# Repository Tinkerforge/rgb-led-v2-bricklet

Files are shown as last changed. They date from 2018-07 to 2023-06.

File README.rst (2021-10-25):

RGB LED Bricklet 2.0
====================

This repository contains the firmware source code and the hardware design
files. The documentation generator configs can be found at
https://github.com/Tinkerforge/generators

Repository Content
------------------

software/:
 * examples/: Examples for all supported languages
 * build/: Compiled files
 * src/: Source code of firmware
 * Makefile: Makefile to build project

hardware/:
 * Contains KiCad project files and additionally schematics as PDF

datasheets/:
 * Contains datasheets for sensors and complex ICs that are used

Hardware
--------

The hardware is designed with the open source EDA Suite KiCad
(http://www.kicad.org). Before you are able to open the files,
you have to install the Tinkerforge kicad-libraries
(https://github.com/Tinkerforge/kicad-libraries). You can either clone
them directly in hardware/ or clone them in a separate folder and
symlink them into hardware/
(ln -s kicad_path/kicad-libraries project_path/hardware). After that you
can open the .pro file in hardware/ with KiCad and from there view and
modify the schematics and the PCB layout.

Software
--------

If you want to do your own Brick/Bricklet firmware development we highly
recommend that you use our build environment setup script and read the
tutorial (https://www.tinkerforge.com/en/doc/Tutorials/Tutorial_Build_Environment/Tutorial.html).

To compile the C code we recommend you to install the newest GNU Arm Embedded
Toolchain (https://launchpad.net/gcc-arm-embedded/+download).
You also need to install bricklib2 (https://github.com/Tinkerforge/bricklib2).

You can either clone it directly in software/src/ or clone it in a
separate folder and symlink it into software/src/
(ln -s bricklib_path/bricklib2 project_path/software/src/). Finally make sure to
have CMake installed (http://www.cmake.org/cmake/resources/software.html).

After that you can build the firmware by invoking make in software/.
The firmware (.zbin) can then be found in software/build/ and uploaded
with brickv (click button "Flashing" on start screen).

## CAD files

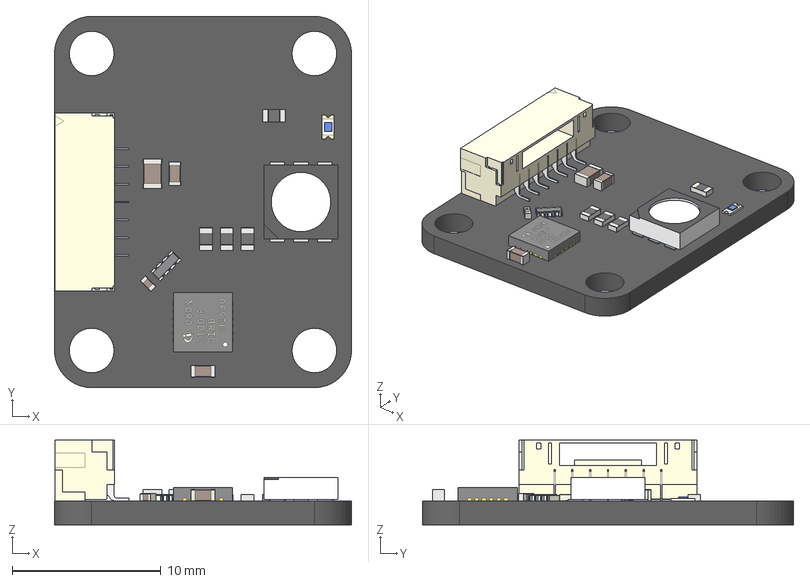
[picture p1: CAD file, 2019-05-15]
hardware/rgb-led-v2.step
20.0 x 25.0 x 5.70 mm
U1_XMC_1100_5B33C1AB
RP1_Cut_5B33C186
R4_R_0603_5B33C176
R3_R_0603_5B33C16C
R2_R_0603_5B33C162
R1_R_0603_5B33C158
P1_BrickletConn_7pin_5B33C140
D2_Fusion_5B33C12D
D1_D_0603_blue_5B33C119
C5_C_0603_5B33C108
C4_C_0603_5B33C0FE
C3_C_0805_5B33C0F4
C1_C_0402_5B33C0EA

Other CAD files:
hardware/rgb-led-v2.FCStd

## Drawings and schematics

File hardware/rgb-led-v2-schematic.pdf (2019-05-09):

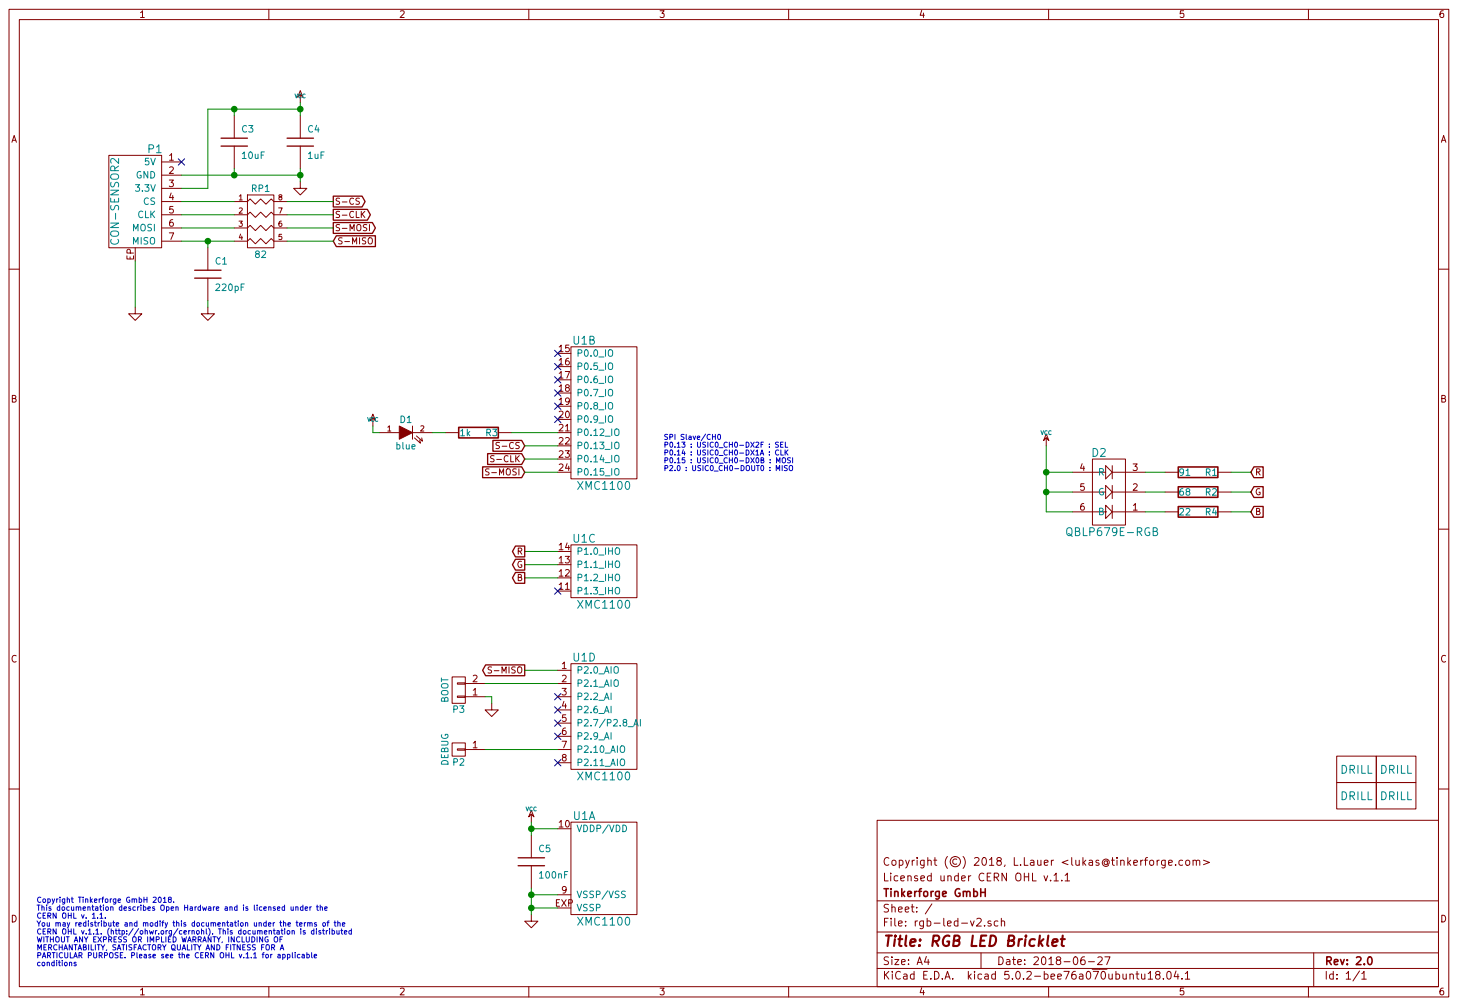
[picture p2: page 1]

SPI Slave/CH0 P0.13 : USIC0_CH0-DX2F : SEL P0.14 : USIC0_CH0-DX1A : CLK

Licensed under CERN OHL v.1.1 Copyright (©) 2018, L.Lauer <lukas@tinkerforge.com>

File: rgb-led-v2.sch Sheet: / Tinkerforge GmbH

Copyright Tinkerforge GmbH 2018. This documentation describes Open Hardware and is licensed under the CERN OHL v. 1.1. You may redistribute and modify this documentation under the terms of the CERN OHL v.1.1. (http://ohwr.org/cernohl). This documentation is distributed WITHOUT ANY EXPRESS OR IMPLIED WARRANTY, INCLUDING OF MERCHANTABILITY, SATISFACTORY QUALITY AND FITNESS FOR A

Id: 1/1 Title: RGB LED Bricklet

PARTICULAR PURPOSE. Please see the CERN OHL v.1.1 for applicable

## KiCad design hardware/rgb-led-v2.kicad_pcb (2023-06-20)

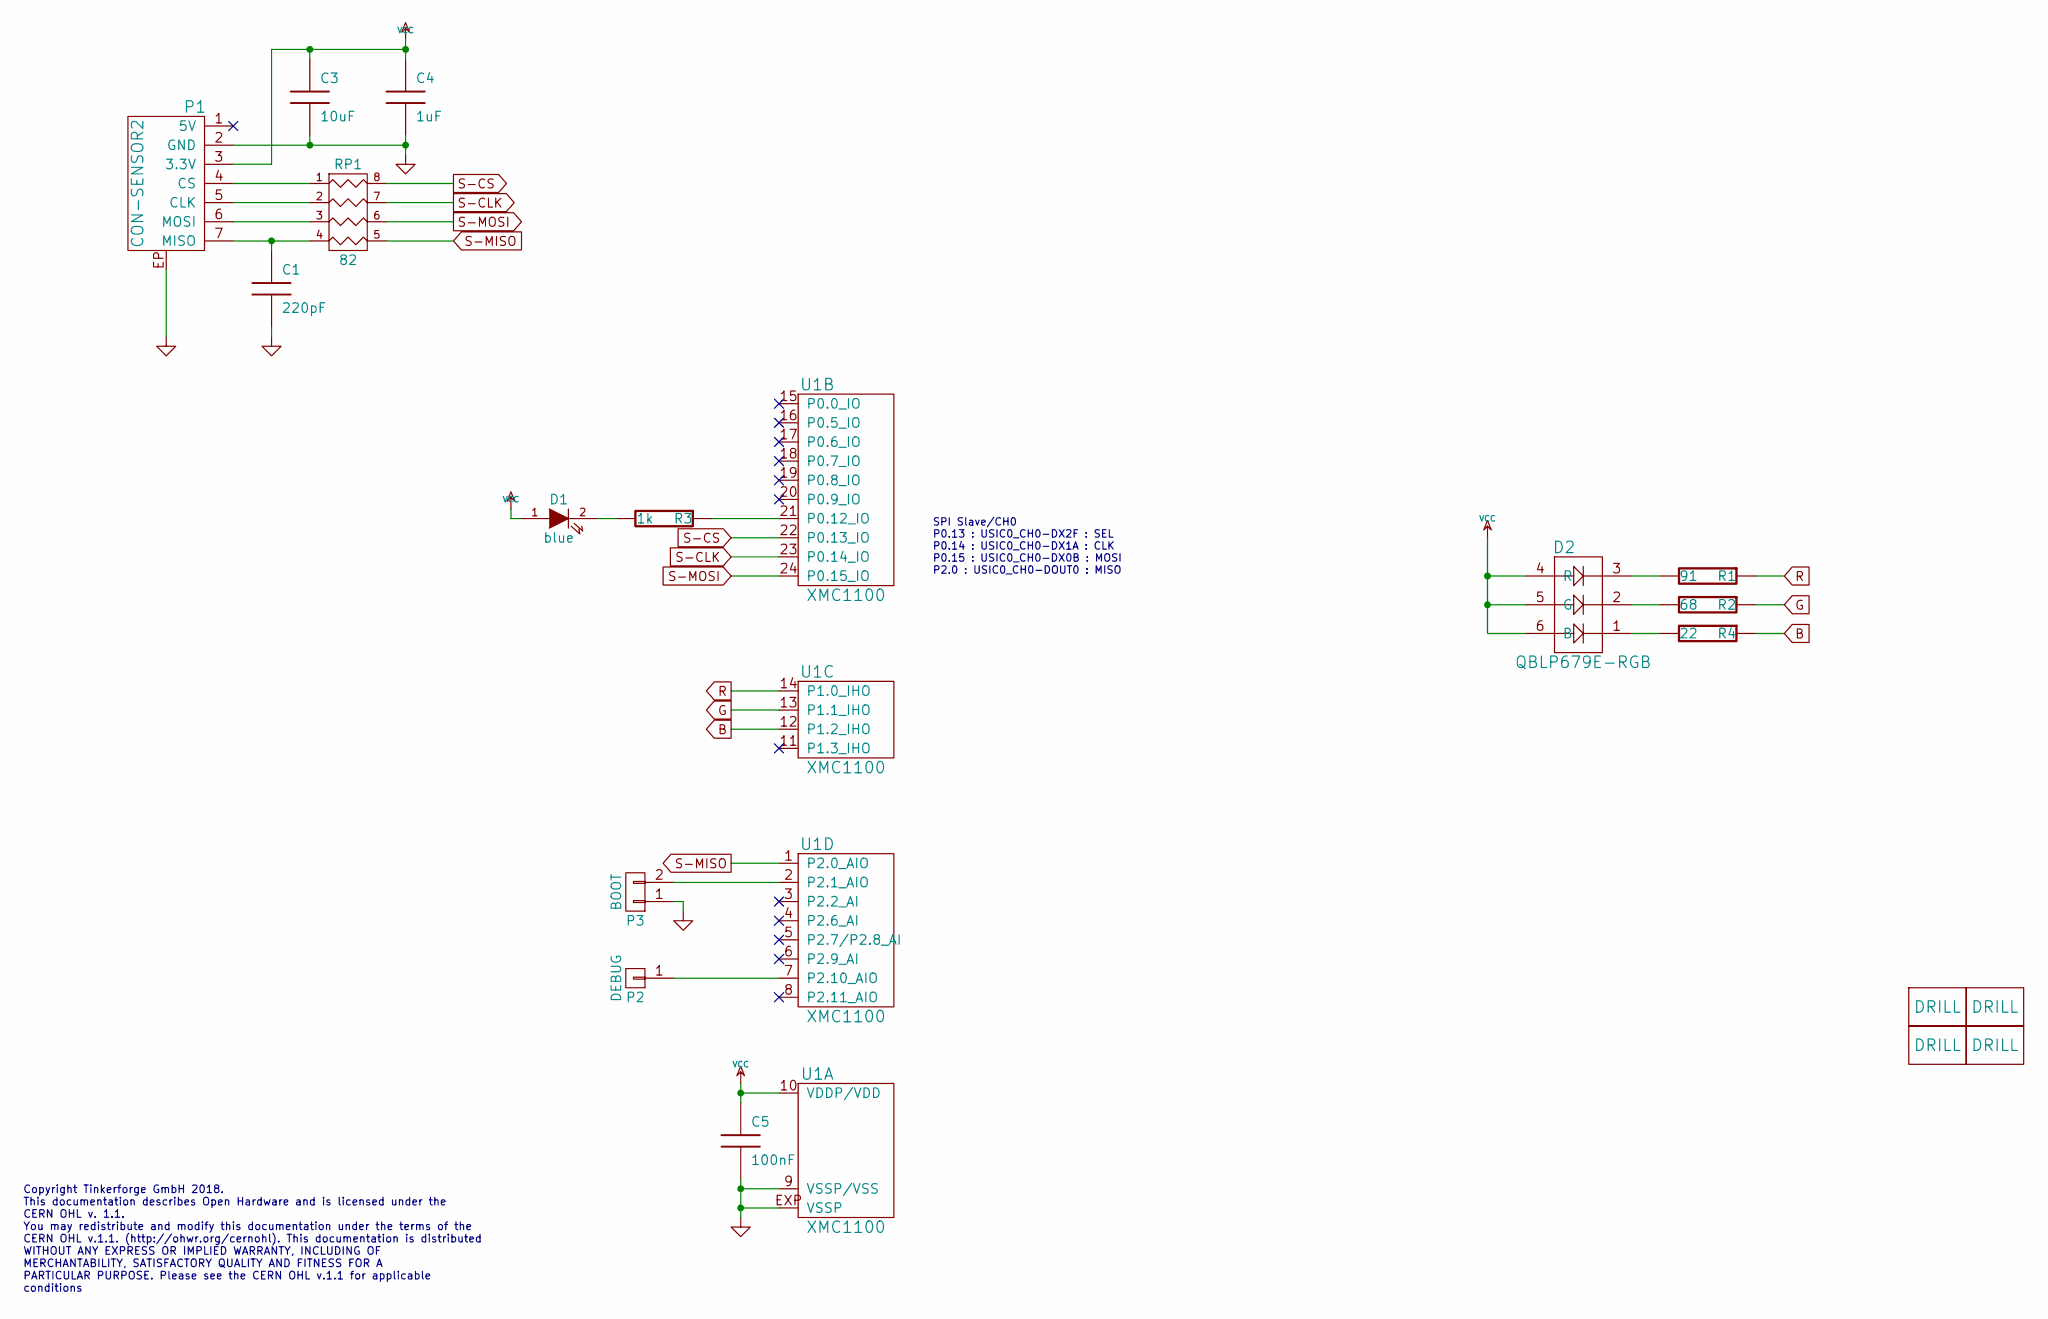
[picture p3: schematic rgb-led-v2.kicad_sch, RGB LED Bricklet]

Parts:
C1: 220pF; C0402F
C3: 10uF; C0805
C4: 1uF; C0603F
C5: 100nF; C0603F
D1: blue; D0603F
D2: QBLP679E-RGB; PLCC6-RGB
P1: CON-SENSOR2
P2: DEBUG; DEBUG_PAD
P3: BOOT; SolderJumper
R1: 91; R0603F
R2: 68; R0603F
R3: 1k; R0603F
R4: 22; R0603F
RP1: 82; 4X0402
U1: XMC1100; QFN24-4x4mm-0.5mm
U3, U4, U5, U6: DRILL; DRILL_NP

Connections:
B: R4.1, U1.12 (P1.2_IHO)
G: R2.1, U1.13 (P1.1_IHO)
GND: C1.2, C3.2, C4.2, C5.2, P1.2 (GND), P1.EP, P3.1, U1.9 (VSSP/VSS), U1.EXP (VSSP)
unnamed: C1.1, P1.7 (MISO), RP1.4
unnamed: D1.2 (K), R3.2
unnamed: D2.1, R4.2
unnamed: D2.2, R2.2
unnamed: D2.3, R1.2
unnamed: P1.4 (CS), RP1.1
unnamed: P1.5 (CLK), RP1.2
unnamed: P1.6 (MOSI), RP1.3
unnamed: P2.1, U1.7 (P2.10_AIO)
unnamed: P3.2, U1.2 (P2.1_AIO)
unnamed: R3.1, U1.21 (P0.12_IO)
R: R1.1, U1.14 (P1.0_IHO)
S-CLK: RP1.7 (R2), U1.23 (P0.14_IO)
S-CS: RP1.8 (R1), U1.22 (P0.13_IO)
S-MISO: RP1.5 (R4), U1.1 (P2.0_AIO)
S-MOSI: RP1.6 (R3), U1.24 (P0.15_IO)
VCC: C3.1, C4.1, C5.1, D1.1 (A), D2.4 (R), D2.5 (G), D2.6 (B), P1.3 (3.3V), U1.10 (VDDP/VDD)

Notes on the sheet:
Copyright Tinkerforge GmbH 2018. This documentation describes Open Hardware and is licensed under the CERN OHL v. 1.1. You may redistribute and modify this documentation under the terms of the CERN OHL v.1.1. (http://ohwr.org/cernohl). This documentation is distributed WITHOUT ANY EXPRESS OR IMPLIE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
SPI Slave/CH0 P0.13 : USIC0_CH0-DX2F : SEL P0.14 : USIC0_CH0-DX1A : CLK P0.15 : USIC0_CH0-DX0B : MOSI P2.0 : USIC0_CH0-DOUT0 : MISO

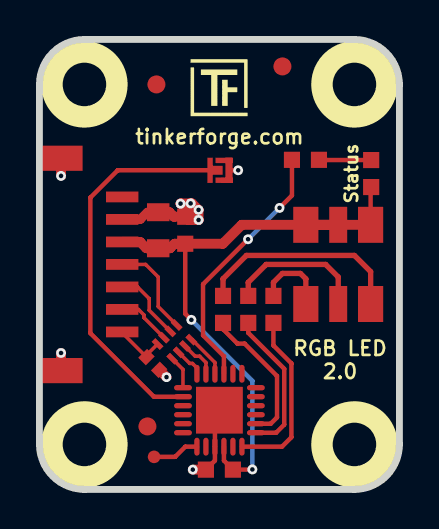
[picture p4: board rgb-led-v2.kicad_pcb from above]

Board: 2 copper layers, 20.0 x 25.0 mm, 24 parts (2 on the bottom side), 20 nets.

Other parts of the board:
Fiducial_Mark: VAL**; Fiducial_Mark
Fiducial_Mark#2, Fiducial_Mark#3: VAL**; Fiducial_Mark
VAL: WEEE_7mm
VAL#2: CE_5mm

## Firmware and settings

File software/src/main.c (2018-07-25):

/* rgb-led-v2-bricklet
 * Copyright (C) 2018 Olaf Lüke <olaf@tinkerforge.com>
 *
 * main.c: Initialization for RGB LED Bricklet 2.0
 *
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
 * You should have received a copy of the GNU Lesser General Public
 * License along with this library; if not, write to the
 * Free Software Foundation, Inc., 59 Temple Place - Suite 330,
 * Boston, MA 02111-1307, USA.
 */

#include <stdio.h>
#include <stdbool.h>

#include "configs/config.h"

#include "bricklib2/bootloader/bootloader.h"
#include "bricklib2/hal/system_timer/system_timer.h"
#include "bricklib2/logging/logging.h"
#include "communication.h"

int main(void) {
	logging_init();
	logd("Start RGB LED Bricklet 2.0\n\r");

	communication_init();

	while(true) {
		bootloader_tick();
		communication_tick();
	}
}

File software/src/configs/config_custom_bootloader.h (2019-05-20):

/* rgb-led-v2-bricklet
 * Copyright (C) 2018 Olaf Lüke <olaf@tinkerforge.com>
 *
 * config_custom_bootloader.h: Bootloader configurations for
 *                             RGB LED Bricklet 2.0
 *
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
 * You should have received a copy of the GNU Lesser General Public
 * License along with this library; if not, write to the
 * Free Software Foundation, Inc., 59 Temple Place - Suite 330,
 * Boston, MA 02111-1307, USA.
 */

#ifndef CONFIG_CUSTOM_BOOTLOADER_H
#define CONFIG_CUSTOM_BOOTLOADER_H

#include "xmc_gpio.h"

// --- Basic defines ---
#define BOOTLOADER_DEVICE_IDENTIFIER   2127
#define BOOTLOADER_HW_VERSION_MAJOR    1
#define BOOTLOADER_HW_VERSION_MINOR    0
#define BOOTLOADER_HW_VERSION_REVISION 0

#define BOOTLOADER_STATUS_LED_PIN      P0_12
#define BOOTLOADER_BOOT_PAD_PIN        P2_1

#define BOOTLOADER_FLASH_EEPROM_SIZE   (4*256)
#define BOOTLOADER_FLASH_SIZE          (16*1024 - BOOTLOADER_FLASH_EEPROM_SIZE)

#define BOOTLOADER_FIX_POINTER_END


// --- SPITFP ---
#define SPITFP_USIC_CHANNEL         USIC0_CH0
#define SPITFP_USIC                 XMC_SPI0_CH0

#define SPITFP_SCLK_PIN             P0_14
#define SPITFP_SCLK_INPUT           XMC_USIC_CH_INPUT_DX1
#define SPITFP_SCLK_SOURCE          0b000 // DX1A

#define SPITFP_SELECT_PIN           P0_13
#define SPITFP_SELECT_INPUT         XMC_USIC_CH_INPUT_DX2
#define SPITFP_SELECT_SOURCE        0b101 // DX2F

#define SPITFP_MOSI_PIN             P0_15
#define SPITFP_MOSI_INPUT           XMC_USIC_CH_INPUT_DX0
#define SPITFP_MOSI_SOURCE          0b001 // DX0B

#define SPITFP_MISO_PIN             P2_0
#define SPITFP_MISO_PIN_AF          (XMC_GPIO_MODE_OUTPUT_PUSH_PULL_ALT6 | P2_0_AF_U0C0_DOUT0)

#define SPITFP_RECEIVE_BUFFER_SIZE  1024
#define SPITFP_RECEIVE_BUFFER_MASK  (SPITFP_RECEIVE_BUFFER_SIZE-1) // If size is power of 2

#define SPITFP_SERVICE_REQUEST_RX   0
#define SPITFP_SERVICE_REQUEST_TX   1

#define SPITFP_IRQ_RX               9
#define SPITFP_IRQ_RX_PRIORITY      2
#define SPITFP_IRQ_TX               10
#define SPITFP_IRQ_TX_PRIORITY      3

#define SPITFP_TX_DATA_POINTER      16
#define SPITFP_TX_SIZE              XMC_USIC_CH_FIFO_SIZE_16WORDS
#define SPITFP_TX_LIMIT             8

#define SPITFP_RX_DATA_POINTER      0
#define SPITFP_RX_SIZE              XMC_USIC_CH_FIFO_SIZE_16WORDS
#define SPITFP_RX_LIMIT             0

// --- BOOTLOADER FUNCTIONS ---

// define bootloader functions to put them into the BootloaderFunctions struct
// These functions are in the bootloader code and can be used from the firmware

#define BOOTLOADER_FUNCTION_SPITFP_TICK
#define BOOTLOADER_FUNCTION_SEND_ACK_AND_MESSAGE
#define BOOTLOADER_FUNCTION_SPITFP_IS_SEND_POSSIBLE
#define BOOTLOADER_FUNCTION_AEABI_IDIV
#define BOOTLOADER_FUNCTION_AEABI_UIDIV
#define BOOTLOADER_FUNCTION_AEABI_IDIVMOD
#define BOOTLOADER_FUNCTION_AEABI_UIDIVMOD
#define BOOTLOADER_FUNCTION_GET_UID
#define BOOTLOADER_FUNCTION_READ_EEPROM_PAGE
#define BOOTLOADER_FUNCTION_WRITE_EEPROM_PAGE

#endif

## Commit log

2018-06-27 Add schematic and layout
    [rgb-led-v2.kicad_pcb, rgb-led-v2.sch]
2018-07-11 Fix origin
    [rgb-led-v2.kicad_pcb]
2018-07-25 Add auto-generated stub firmware
    [cmake_config_custom.txt]
2019-01-09 fix broken bottom layer, copper filled everything
    [rgb-led-v2.kicad_pcb]
2019-01-17 drc check
    [rgb-led-v2.kicad_pcb]
2019-01-29 fix schematic version, specify rgb led
    [rgb-led-v2.kicad_pcb, rgb-led-v2.sch]
2019-01-29 add kicad symbol table
2019-02-14 Add RGB LED API and driver implementation
2019-02-22 changed procesor to XMC1100
    [rgb-led-v2.kicad_pcb, rgb-led-v2.sch]
2019-05-09 add schematic
2019-05-10 specify led position
    [rgb-led-v2.kicad_pcb]
2019-05-15 add 3d data
    [rgb-led-v2.FCStd, rgb-led-v2.kicad_pcb, rgb-led-v2.step]
2019-05-20 Use bootloader fix in all new Bricklets
    [config_custom_bootloader.h]
2020-09-02 uc: Add example driver note.
2021-10-25 Update KiCad link
    https://www.kicad.org/blog/2021/10/Avoid-links-to-former-kicad-domain/
2023-06-20 move to new kicad version
    [rgb-led-v2.kicad_pcb, rgb-led-v2.kicad_sch, rgb-led-v2.sch]
